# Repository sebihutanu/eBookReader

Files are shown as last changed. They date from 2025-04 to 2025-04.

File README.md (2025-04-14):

# OpenBook 

<p align="center">
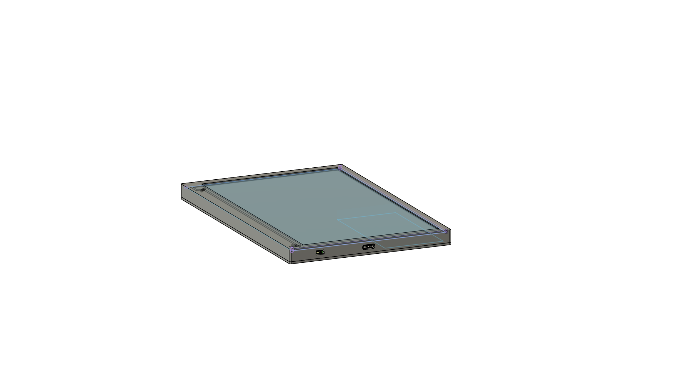
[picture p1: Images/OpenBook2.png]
  
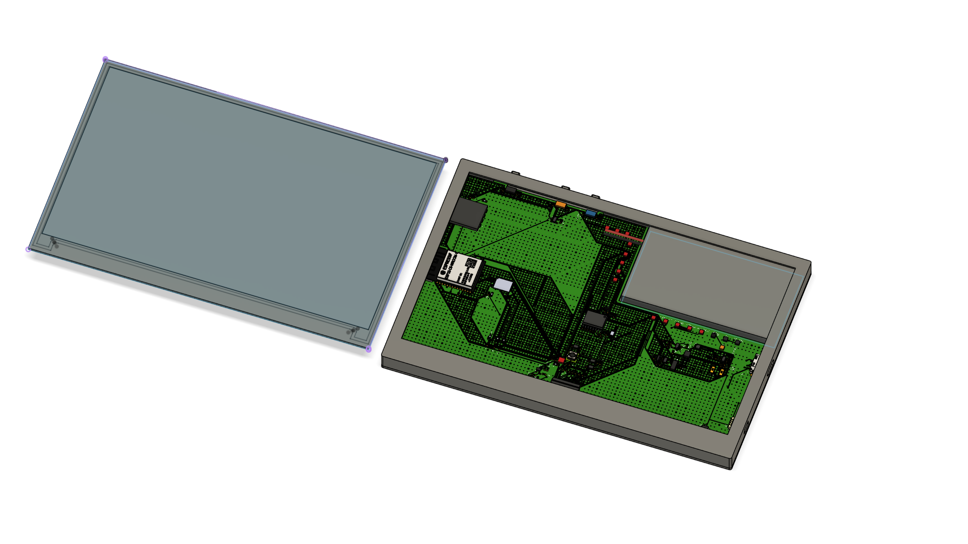
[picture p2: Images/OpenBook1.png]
  
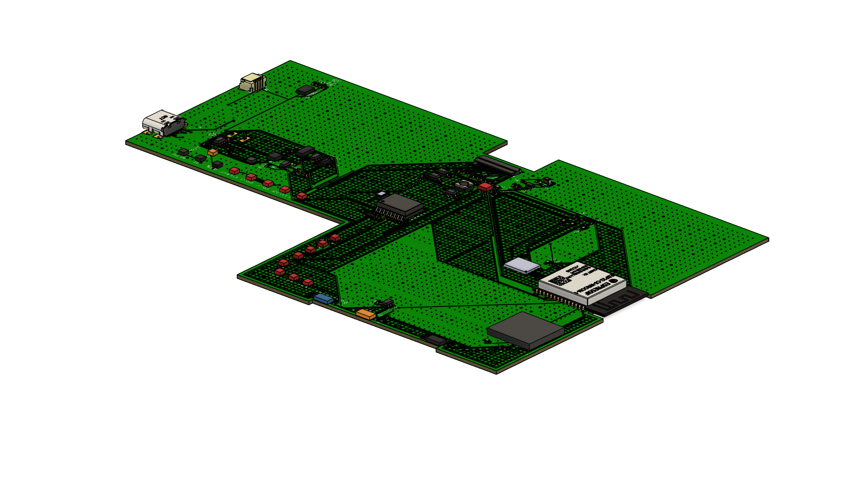
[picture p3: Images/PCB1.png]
  
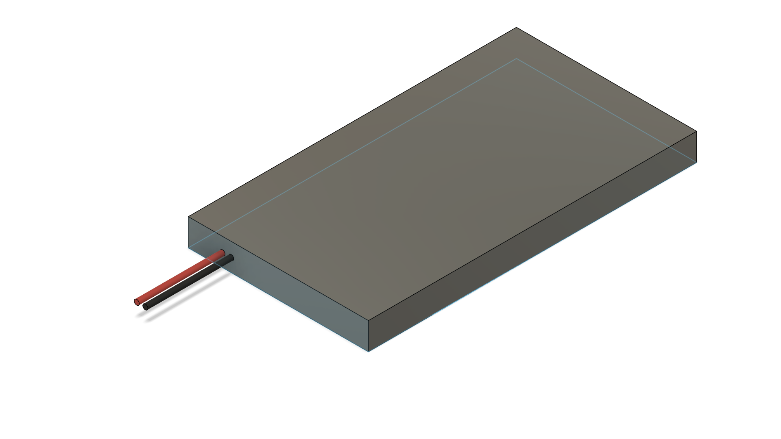
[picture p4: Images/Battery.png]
  
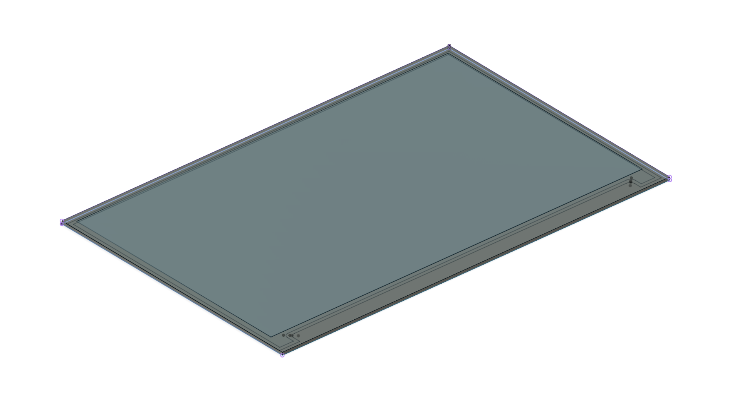
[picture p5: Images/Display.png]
  
</p>

## Implementation Steps

### Schematic Design
I used all the required modules (ESP32-C6, BME688, RTC, Display, etc.) based on the reference schematic. I maintained consistent net naming and used components from the provided library.

### Component Placement
I followed the recommended placement, especially for the ESP32 module (antenna area), buttons, USB port, and display header. All components were placed on the TOP layer, as required.

### Manual Routing
Power traces (3V3, VBAT, VBUS, VUSB, VCC, EPD_3V3, EPD_3V3_C) were routed using a width of 0.3 mm, and signal traces were routed with 0.15 mm width.

### Ground Planes & Via Stitching
I created ground planes on both Top and Bottom layers, connected through via stitching. The area under the ESP32 antenna was excluded (no copper or vias) to ensure proper wireless performance.

### Silkscreen & Test Pads
All components were labeled using only their reference designators (R1, C1, etc.) without values. Test pads were clearly labeled in silkscreen (TX, RX, MISO, VBAT, GND, etc.).

### 3D Model & Enclosure
The final 3D model includes the PCB, display, battery (modeled based on datasheet dimensions), and the official provided enclosure. I verified the alignment of the USB port, buttons, and display header with the housing.

## Component List

- **ESP32-C6-WROOM-1-N8**: Main microcontroller. Supports Wi-Fi 6 (2.4GHz), Bluetooth 5, Thread, and Zigbee. Used for control logic and communication. 
    - **Price**: 14.70 RON
    - **Quantity**: 1
    - **Link**: https://ro.mouser.com/datasheet/2/891/Espressif_ESP32_C6_WROOM_1__Datasheet_V0_1_PRELIMI-3239987.pdf
    - **Datasheet**: https://ro.mouser.com/ProductDetail/Espressif-Systems/ESP32-C6-WROOM-1-N8?qs=8Wlm6%252BaMh8ST02Gmwp74cw%3D%3D

- **W25Q512JVEIQ**: 64MB NOR flash memory. Stores firmware, assets, or user data. Communicates via SPI.
    - **Price**: 28.91 RON
    - **Quantity**: 1
    - **Link**: https://ro.mouser.com/ProductDetail/Winbond/W25Q512JVEIQ?qs=l7cgNqFNU1jw6svr3at6tA%3D%3D
    - **Datasheet**: https://ro.mouser.com/datasheet/2/949/Winbond_W25Q512JV_Datasheet-3240039.pdf

- **MAX17048G+T10**: Fuel gauge IC. Provides battery charge level monitoring via I2C.
    - **Price**: 21.19 RON
    - **Quantity**: 1
    - **Link**: https://ro.mouser.com/ProductDetail/Analog-Devices-Maxim-Integrated/MAX17048G%2bT10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
    - **Datasheet**: https://ro.mouser.com/datasheet/2/609/MAX17048_MAX17049-3469099.pdf

- **MCP73831**: Li-Ion/Li-Poly battery charging IC. Controls charging current and status indication.
    - **Price**: 3.72 RON
    - **Quantity**: 1
    - **Link**: https://ro.mouser.com/ProductDetail/Microchip-Technology/MCP73831-2ACI-MC?qs=hH%252BOa0VZEiBneYTVdpuVdg%3D%3D
    - **Datasheet**: https://ro.mouser.com/datasheet/2/268/MCP73831_Family_Data_Sheet_DS20001984H-3441711.pdf

- **XC6220A331MR-G**: Low-dropout (LDO) voltage regulator. Converts USB input (5V) to stable 3.3V for the system.
    - **Price**: 2.50 RON
    - **Quantity**: 1
    - **Link**: https://ro.mouser.com/ProductDetail/Torex-Semiconductor/XC6220A331MR-G?qs=AsjdqWjXhJ8ZSWznL1J0gg%3D%3D
    - **Datasheet**: https://ro.mouser.com/datasheet/2/760/xc6220-3371556.pdf

- **DS3231SN#**: High-accuracy real-time clock (RTC) with battery backup. Communicates over I2C.
    - **Price**: 7.23 RON
    - **Quantity**: 1
    - **Link**: https://ro.mouser.com/ProductDetail/Maxim-Integrated/DS3231SN%23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
    - **Datasheet**: https://ro.mouser.com/datasheet/2/609/DS3231-DS3231M-DS3231S

- **BME688 (ESP32_WROVER_BME688)**: Environmental sensor. Measures temperature, humidity, pressure, and gas (VOC). Uses I2C.
    - **Price**: 48.90 RON
    - **Quantity**: 1
    - **Link**: https://ro.mouser.com/ProductDetail/Bosch-Sensortec/BME688?qs=IS%252B4QmGtzzqQoVDscqwx3A%3D%3D
    - **Datasheet**: https://ro.mouser.com/datasheet/2/783/bst_bme688_fl000-2307034.pdf

- **CPH3225A**: Supercapacitor used for RTC backup power.
    - **Price**: 11.04 RON
    - **Quantity**: 1
    - **Link**: https://ro.mouser.com/ProductDetail/Seiko-Semiconductors/CPH3225A?qs=3etwrb1wR%252BhUOph6lAO7eg%3D%3D
    - **Datasheet**: https://ro.mouser.com/datasheet/2/360/Seiko_Instruments_MicroBattery_E_20230330_2024Jan_-3561061.pdf

- **744043680IND_4828-WE-TPC_WRE**: Inductor (68µH). Used for filtering or part of the power supply circuit.
    - **Price**: 6.44 RON
    - **Quantity**: 1
    - **Link**: https://ro.mouser.com/ProductDetail/Wurth-Elektronik/744043680?qs=PGXP4M47uW6VkZq%252BkzjrHA%3D%3D
    - **Datasheet**: https://www.we-online.com/components/products/datasheet/744043680.pdf

- **MBR0530**: Schottky diodes. Used for reverse voltage protection and power path steering.
    - **Price**: 0.90 RON
    - **Quantity**: 3
    - **Link**: https://ro.mouser.com/ProductDetail/onsemi/MBR0530T3G?qs=3JMERSakebpEmdUS6GetdQ%3D%3D
    - **Datasheet**: https://www.onsemi.com/PowerSolutions/product.do?id=MBR0530T3G

- **BD5229G-TR**: Voltage detector. Used for power-on reset or system supervisory functions.
    - **Price**: 3.72 RON
    - **Quantity**: 1
    - **Link**: https://ro.mouser.com/ProductDetail/ROHM-Semiconductor/BD5229G-TR?qs=4kLU8WoGk0vvnhrrYwdszw%3D%3D
    - **Datasheet**: https://fscdn.rohm.com/en/products/databook/datasheet/ic/power/voltage_detector/bd52xxg-e.pdf

- **SI1308EDL-T1-GE3**: N-channel MOSFET. Used for switching or power control.
    - **Price**: 2.07 RON
    - **Quantity**: 1
    - **Link**: https://ro.mouser.com/ProductDetail/Vishay-Semiconductors/SI1308EDL-T1-GE3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
    - **Datasheet**: https://www.vishay.com/doc?63399

- **DMG2305UX**: P-channel MOSFET. Used in power switching or display driving.
    - **Price**: 0.95 RON
    - **Quantity**: 2
    - **Link**: https://ro.mouser.com/ProductDetail/Diodes-Incorporated/DMG2305UX-7?qs=L1DZKBg7t5F%2FNBHrjfxC%252Bg%3D%3D
    - **Datasheet**: https://www.diodes.com/assets/Datasheets/DMG2305UX.pdf

- **USBLC6-2SC6Y**: ESD protection array for USB lines.
    - **Price**: 2.16 RON
    - **Quantity**: 1
    - **Link**: https://ro.mouser.com/ProductDetail/STMicroelectronics/USBLC6-2SC6Y?qs=gNDSiZmRJS%2FOgDexvXkdow%3D%3D
    - **Datasheet**: https://ro.mouser.com/datasheet/2/389/usblc6_2sc6y-1852505.pdf

- **PGB1010603MR**: ESD suppressor / protection component for various I/O lines.
    - **Price**: 1.98 RON
    - **Quantity**: 6
    - **Link**: https://ro.mouser.com/ProductDetail/Littelfuse/PGB1010603MR?qs=gu7KAQ731URLg4GSnNNN7Q%3D%3D
    - **Datasheet**: https://www.littelfuse.com/assetdocs/pulseguard-esd-suppressors-pgb1-datasheet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

- **TPTP20R**: Test pads. Used for debugging and electrical measurements (e.g. TX, RX, GND, etc.).

- **FH34SRJ-24S-0.5SH(99)**: FPC connector. Used for connecting the e-paper display.
    - **Price**: 12.87 RON
    - **Quantity**: 1
    - **Link**: https://ro.mouser.com/ProductDetail/Hirose-Connector/FH34SRJ-24S-0.5SH99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
    - **Datasheet**: https://ro.mouser.com/datasheet/2/185/FH34SRJ_24S_0_5SH_99__CL0580_1255_6_99_2DDrawing_0-1615044.pdf

- **SAMACSYS_PARTS_USB4110-GF-A**: USB Type-C connector. Used for charging and potential data communication.
    - **Price**: 5.84 RON
    - **Quantity**: 1
    - **Link**: https://ro.mouser.com/ProductDetail/GCT/USB4110-GF-A?qs=KUoIvG%2F9IlYiZvIXQjyJeA%3D%3D
    - **Datasheet**: https://ro.mouser.com/datasheet/2/837/GCT_USB4110_Product_Drawing___20k_cycles-3455479.pdf

- **112A-TAAR-R03_ATTEND3DMODEL**: MicroSD card connector (Push-Push type).
    - **Price**: 7.08 RON
    - **Quantity**: 1
    - **Link**: https://www.digikey.in/en/products/detail/attend-technology/112A-TAAR-R03/17633923
    - **Datasheet**: https://www.attend.com.tw/data/download/file/112A-TAAR-R03_Spec.pdf

- **QWIIC_CONNECTORJS-1MM**: Qwiic I2C connector. Simplifies connecting I2C peripherals.
    - **Price**: 2.30 RON
    - **Quantity**: 1
    - **Link**: https://www.sparkfun.com/qwiic-jst-connector-smd-4-pin-horizontal.html
    - **Datasheet**: https://cdn.sparkfun.com/assets/parts/1/2/2/8/9/Qwiic_Connector_Datasheet.pdf

- **BUTTON_CUSYOMV1**: Push buttons for user input. Includes RESET, BOOT, and FUNCTION buttons.

- **SJ**: Solder jumper. Used to configure hardware options or break/join signals manually.
    - **Price**: 0.55 RON
    - **Quantity**: 1
    - **Link**: https://ro.mouser.com/ProductDetail/Walsin/WR08X000-PGL?qs=1mbolxNpo8eMafhL38cnrw%3D%3D
    - **Datasheet**: https://www.farnell.com/datasheets/2813407.pdf

- **ESP32C6_VARISTORCN1812**: Varistor. Protects against voltage spikes on power lines.
    - **Price**: 2.68 RON
    - **Quantity**: 1
    - **Link**: https://ro.mouser.com/ProductDetail/Bourns/MOV-14D101K?qs=CQ3B1E%252BbPs1zZItCYuJaag%3D%3D
    - **Datasheet**: https://www.mouser.com/datasheet/2/54/MOV14D-57555.pdf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

- **ESP32_WROVER_AVX (SD0805S020S1R0)**: Schottky diode (another variant). Also used for power line protection.
    - **Price**: 1.46 RON
    - **Quantity**: 1
    - **Link**: https://ro.mouser.com/ProductDetail/KYOCERA-AVX/SD0805S020S1R0?qs=jCA%252BPfw4LHbpkAoSnwrdjw%3D%3D
    - **Datasheet**: https://ro.mouser.com/datasheet/2/40/schottky-3165252.pdf

- **ADAFRUIT_LEDCHIP-LED0603**: Surface-mount LED (0603). Used as charge indicator or status LED.
    - **Price**: 0.50 RON
    - **Quantity**: 1
    - **Link**: https://www.niden.ro/led-uri-smd/4560-led-smd-0603-alb-rece.html
    - **Datasheet**: https://www.mouser.com/datasheet/2/423/LSM0603472V_(1)-1379786.pdf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

- **EAGLE-LTSPICE_CC0402 / RR0402 / RCL_CPOL-EUCT3528**: Capacitors and resistors in SMD packages. Used for decoupling, filtering, and biasing.
    - **Price**: 0.10 RON
    - **Quantity**: 1
    - **Link**: https://www.digikey.com/en/products/detail/rohm-semiconductor/CC0402/1000000
    - **Datasheet**: https://www.rohm.com/datasheet/CC0402

- **CC0402**: Capacitor (0402 package). Used for decoupling and filtering.
    - **Price**: 0.52 RON
    - **Quantity**: 24
    - **Link**: https://ro.mouser.com/ProductDetail/TAIYO-YUDEN/MCASU105SCG100JFNA01?qs=HFfMDpzxxd3IzDXquDJtfA%3D%3D
    - **Datasheet**: https://ro.mouser.com/datasheet/2/396/TAIYO_YUDEN_04_29_2024_MCASU105SCG100JFNA01_SS-3451431.pdf

- **RR0402**: Resistor (0402 package). Used for pull-up/pull-down or biasing.
    - **Price**: 0.27 RON
    - **Quantity**: 24
    - **Link**: https://ro.mouser.com/ProductDetail/Vishay-Dale/CRCW04020000Z0EEHP?qs=Imq1NPwxi74NTc567q7flQ%3D%3D
    - **Datasheet**: https://www.vishay.com/doc?20043

- **RCL_CPOL-EUCT3528**: Capacitor (EUCT3528 package). Used for decoupling and filtering.
    - **Price**: 6.50 RON
    - **Quantity**: 1
    - **Link**: https://ro.mouser.com/ProductDetail/Vishay-Sprague/TX3B336K016C1000?qs=HFfMDpzxxd327XT3TleiYg%3D%3D
    - **Datasheet**: https://www.vishay.com/doc?40283

- **Battery**: 3.7V Li-Ion battery (not included in the schematic). Used for powering the device when not connected to USB.
    - **Price**: 29.50 RON
    - **Quantity**: 1
    - **Link**: https://www.tme.eu/Document/e0683d8c34e6d878124489f71bffb6ee/cel0014.pdf
    - **Datasheet**: https://www.tme.eu/Document/e0683d8c34e6d878124489f71bffb6ee/cel0014.pdf

- **Display**: E-paper display (not included in the schematic). Used for displaying information to the user.
    - **Price**: 258.85 RON
    - **Quantity**: 1
    - **Link**: https://www.waveshare.com/7.5inch-e-paper-hat.htm
    - **Datasheet**: https://files.waveshare.com/upload/6/60/7.5inch_e-Paper_V2_Specification.pdf
    
> **Total Cost**: 485.50 RON (approx. 100 EUR)

> **Note:** All standard resistors and capacitors are SMD 0402 unless otherwise specified. Decoupling capacitors (100nF) are placed close to IC power pins for stability.

## Block Diagram

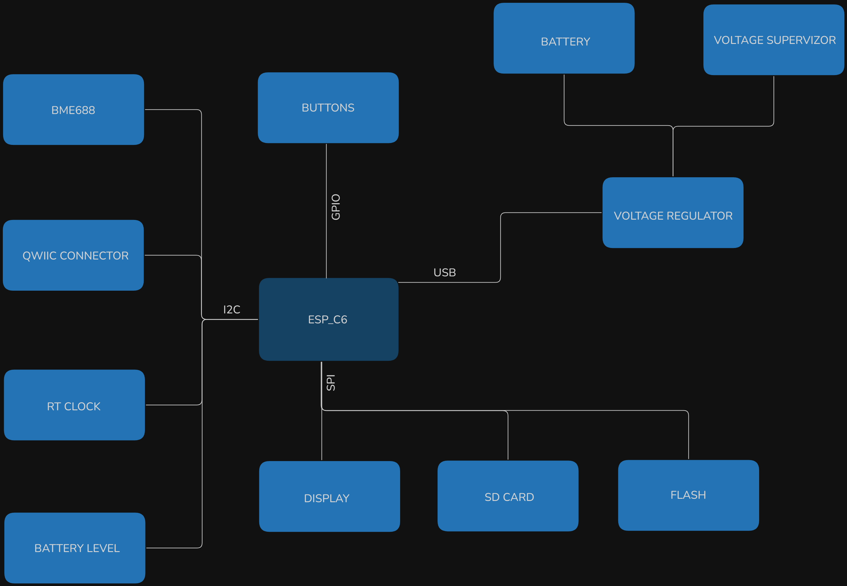
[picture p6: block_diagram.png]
Block Diagram


## ESP32-C6 Pin Utilization

| ESP32-C6 Pin | Signal Name | Connected Component | Description / Purpose |
|---|---|---|---|
| EN | RESET | - | Reset input, active HIGH; used to restart the microcontroller |
| GPIO0 | INT_RTC | RTC (DS3231) | External interrupt input from RTC alarm |
| GPIO1 | 32KHZ | RTC (DS3231) | 32 kHz reference clock from RTC |
| GPIO2 | MISO | SD card / Flash | SPI MISO line for data input |
| GPIO3 | EPD_BUSY | E-paper display | Busy status from EPD module |
| GPIO4 | SS_SD | SD card | Chip select for SD card on SPI |
| GPIO5 | EPD_DC | E-paper display | Data/command control signal for EPD |
| GPIO6 | SCK | SPI bus | Serial clock for SPI communication |
| GPIO7 | MOSI | SPI bus | SPI data output |
| GPIO8 | GPIO8 | - | Unused general-purpose pin (test/debug) |
| GPIO9 | IO/BOOT | Push-button | Used to enter bootloader mode for programming |
| GPIO10 | EPD_CS | E-paper display | Chip select for EPD module |
| GPIO11 | FLASH_CS | External flash (W25Q512) | Chip select for SPI flash memory |
| GPIO12 | USB_D- | USB-C connector | USB differential data line (negative) |
| GPIO13 | USB_D+ | USB-C connector | USB differential data line (positive) |
| GPIO15 | IO/CHANGE | Push-button | General-purpose button input |
| GPIO16 (TXD) | TX | UART | Serial transmission line |
| GPIO17 (RXD) | RX | UART | Serial reception line |
| GPIO18 | RTC_RST | RTC (DS3231) | Reset control for RTC |
| GPIO19 | I2C_RST | I2C devices | I2C reset or control signal |
| GPIO20 | EPD_3V3_C | E-paper display | Power control or monitoring line for EPD |
| GPIO21 | SDA | I2C devices (BME688, Fuel Gauge) | I2C data line for sensors and peripherals |
| GPIO22 | SCL | I2C devices (BME688, Fuel Gauge) | I2C clock line for sensors and peripherals |
| GPIO23 | EPD_RST | E-paper display | Reset signal for the EPD display |

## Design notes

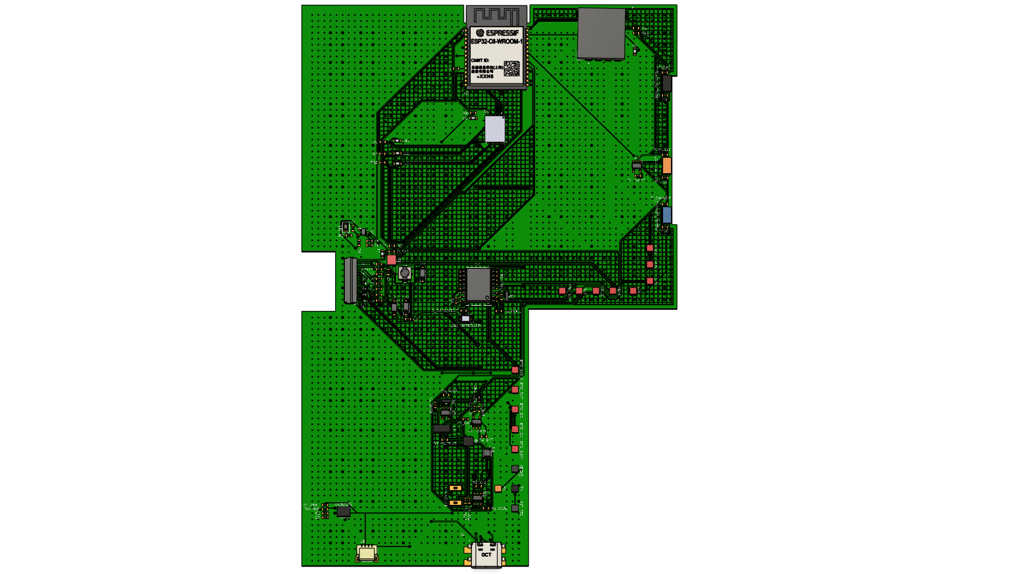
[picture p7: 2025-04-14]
Images/PCB2.png

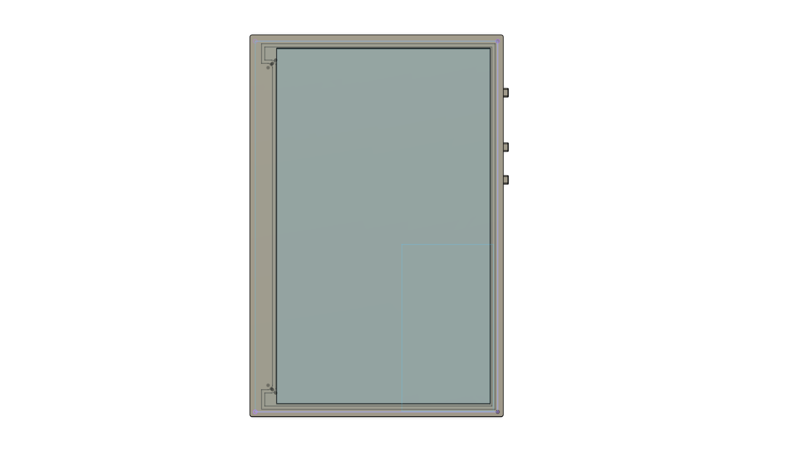
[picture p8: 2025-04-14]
Images/OpenBook3.png

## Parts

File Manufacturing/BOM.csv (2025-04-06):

Qty | Value | Device | Package | Parts | Description | ARROW_PART_NUMBER | ARROW_PRICE-STOCK | AVAILABILITY | CENTROID_NOT_SPECIFIED | CHECK_PRICES | COPYRIGHT | DATASHEET | DESCRIPTION | DIGIKEY_DESCRIPTION | DIGIKEY_PART_NUMBER | HEIGHT | LEAD_FREE | MANUFACTURER_NAME | MANUFACTURER_PART_NUMBER | MF | MFR_NAME | MOUSER_PART_NUMBER | MOUSER_PRICE-STOCK | MP | MPN | PACKAGE | POPULARITY | PREFIX | PRICE | PROD_ID | PURCHASE-URL | ROHS | SNAPEDA_LINK | SPICEMODEL | SPICEPREFIX | TEMPERATURE_RANGE_HIGH | TEMPERATURE_RANGE_LOW | TP_SIGNAL_NAME | VALUE
1 |  | ADAFRUIT_LEDCHIP-LED0603 | ADAFRUIT_CHIP-LED0603 | CHG_LED | LED
1 |  | EAGLE-LTSPICE_CC0402 | EAGLE-LTSPICE_C0402 | C2 | CAPACITOR, European symbol |  |  |  |  |  |  |  |  |  |  |  |  |  |  |  |  |  |  |  |  |  |  |  |  |  |  |  |  | NONE | C
6 |  | ESP32_WROVER_EAGLE-LTSPICE_RR0402 | ESP32_WROVER_EAGLE-LTSPICE_R0402 | R5, R7, R8, R9, R10, R12 | RESISTOR, European symbol |  |  |  |  |  |  |  |  |  |  |  |  |  |  |  |  |  |  |  |  |  |  |  |  |  |  |  |  | NONE | R
1 |  | SJ | SJ | SJ1 | SMD solder JUMPER |  |  |  |  |  |  |  |  |  |  |  |  |  |  |  |  |  |  |  |  |  | 3
1 | 0.1uF/50V | EAGLE-LTSPICE_CC0402 | EAGLE-LTSPICE_C0402 | EPD_C5 | CAPACITOR, European symbol |  |  |  |  |  |  |  |  |  |  |  |  |  |  |  |  |  |  |  |  |  |  |  |  |  |  |  |  | NONE | C
1 | 0.47 | ESP32_WROVER_EAGLE-LTSPICE_RR0402 | ESP32_WROVER_EAGLE-LTSPICE_R0402 | R3 | RESISTOR, European symbol |  |  |  |  |  |  |  |  |  |  |  |  |  |  |  |  |  |  |  |  |  |  |  |  |  |  |  |  | NONE | R
1 | 100K | ESP32_WROVER_EAGLE-LTSPICE_RR0402 | ESP32_WROVER_EAGLE-LTSPICE_R0402 | R1_PWRUSB | RESISTOR, European symbol |  |  |  |  |  |  |  |  |  |  |  |  |  |  |  |  |  |  |  |  |  |  |  |  |  |  |  |  | NONE | R
6 | 100nF | EAGLE-LTSPICE_CC0402 | EAGLE-LTSPICE_C0402 | C1, C4_USB, C6, C8, C10, C_DELAY | CAPACITOR, European symbol |  |  |  |  |  |  |  |  |  |  |  |  |  |  |  |  |  |  |  |  |  |  |  |  |  |  |  |  | NONE | C
1 | 100nF | ESP32_WROVER_EAGLE-LTSPICE_CC0402 | ESP32_WROVER_EAGLE-LTSPICE_C0402 | C9 | CAPACITOR, European symbol |  |  |  |  |  |  |  |  |  |  |  |  |  |  |  |  |  |  |  |  |  |  |  |  |  |  |  |  | NONE | C
1 | 100uF TANT | RCL_CPOL-EUCT3528 | RCL_CT3528 | C3 | POLARIZED CAPACITOR, European symbol |  |  |  |  |  |  |  |  |  |  |  |  |  |  |  |  |  |  |  |  |  | 0 |  |  |  |  |  |  |  | C
10 | 10K | ESP32_WROVER_EAGLE-LTSPICE_RR0402 | ESP32_WROVER_EAGLE-LTSPICE_R0402 | R1, R1_PINH, R1_PINH1, R2-PINH, R2-PINH1, R4, R_BOOT, R_CHANGE, R_CL1, R_RESET | RESISTOR, European symbol |  |  |  |  |  |  |  |  |  |  |  |  |  |  |  |  |  |  |  |  |  |  |  |  |  |  |  |  | NONE | R
1 | 10uF | ESP32_WROVER_EAGLE-LTSPICE_CC0402 | ESP32_WROVER_EAGLE-LTSPICE_C0402 | C7 | CAPACITOR, European symbol |  |  |  |  |  |  |  |  |  |  |  |  |  |  |  |  |  |  |  |  |  |  |  |  |  |  |  |  | NONE | C
1 | 112A-TAAR-R03_ATTEND3DMODEL | 112A-TAAR-R03_ATTEND3DMODEL | 112ATAARR03ATTEND | J4 | Micro SD Card Socket, Push-Push Type, Top Mount, SMT, H=1.83mm, 10u
1 | 15 | ESP32_WROVER_EAGLE-LTSPICE_RR0402 | ESP32_WROVER_EAGLE-LTSPICE_R0402 | R_CAPACITOR | RESISTOR, European symbol |  |  |  |  |  |  |  |  |  |  |  |  |  |  |  |  |  |  |  |  |  |  |  |  |  |  |  |  | NONE | R
1 | 1uF | EAGLE-LTSPICE_CC0402 | EAGLE-LTSPICE_C0402 | C5 | CAPACITOR, European symbol |  |  |  |  |  |  |  |  |  |  |  |  |  |  |  |  |  |  |  |  |  |  |  |  |  |  |  |  | NONE | C
9 | 1uF/50V | EAGLE-LTSPICE_CC0402 | EAGLE-LTSPICE_C0402 | EPD_C1, EPD_C2, EPD_C6, EPD_C7, EPD_C8, EPD_C9, EPD_C10, EPD_C11, EPD_C12 | CAPACITOR, European symbol |  |  |  |  |  |  |  |  |  |  |  |  |  |  |  |  |  |  |  |  |  |  |  |  |  |  |  |  | NONE | C
1 | 2.2 | ESP32_WROVER_EAGLE-LTSPICE_RR0402 | ESP32_WROVER_EAGLE-LTSPICE_R0402 | R2 | RESISTOR, European symbol |  |  |  |  |  |  |  |  |  |  |  |  |  |  |  |  |  |  |  |  |  |  |  |  |  |  |  |  | NONE | R
1 | 200 | ESP32_WROVER_EAGLE-LTSPICE_RR0402 | ESP32_WROVER_EAGLE-LTSPICE_R0402 | R1_BAT | RESISTOR, European symbol |  |  |  |  |  |  |  |  |  |  |  |  |  |  |  |  |  |  |  |  |  |  |  |  |  |  |  |  | NONE | R
2 | 20V/4.2A/52mO/1.4W | ESP32_WROVER_SPARKFUN-DISCRETESEMI_MOSFET_PCH-DMG2305UX-7 | ESP32_WROVER_SPARKFUN-DISCRETESEMI_SOT23-3 | Q1, Q2 | P-channel MOSFETs |  |  |  |  |  |  |  |  |  |  |  |  |  |  |  |  |  |  |  |  |  |  |  |  | TRAN-14388 |  |  |  |  |  |  |  |  | 20V/4.2A/52mO/1.4W
1 | 2K | ESP32_WROVER_EAGLE-LTSPICE_RR0402 | ESP32_WROVER_EAGLE-LTSPICE_R0402 | R2_BAT | RESISTOR, European symbol |  |  |  |  |  |  |  |  |  |  |  |  |  |  |  |  |  |  |  |  |  |  |  |  |  |  |  |  | NONE | R
4 | 4.7uF | EAGLE-LTSPICE_CC0402 | EAGLE-LTSPICE_C0402 | C1_BAT, C1_BAT1, C2_BAT, C5_USB | CAPACITOR, European symbol |  |  |  |  |  |  |  |  |  |  |  |  |  |  |  |  |  |  |  |  |  |  |  |  |  |  |  |  | NONE | C
1 | 4.7uF | ESP32_WROVER_EAGLE-LTSPICE_CC0402 | ESP32_WROVER_EAGLE-LTSPICE_C0402 | C1_BAT2 | CAPACITOR, European symbol |  |  |  |  |  |  |  |  |  |  |  |  |  |  |  |  |  |  |  |  |  |  |  |  |  |  |  |  | NONE | C
1 | 4.7uF/25V | EAGLE-LTSPICE_CC0402 | EAGLE-LTSPICE_C0402 | C4 | CAPACITOR, European symbol |  |  |  |  |  |  |  |  |  |  |  |  |  |  |  |  |  |  |  |  |  |  |  |  |  |  |  |  | NONE | C
2 | 5k1 | ESP32_WROVER_EAGLE-LTSPICE_RR0402 | ESP32_WROVER_EAGLE-LTSPICE_R0402 | R2-USB, R2-USB1 | RESISTOR, European symbol |  |  |  |  |  |  |  |  |  |  |  |  |  |  |  |  |  |  |  |  |  |  |  |  |  |  |  |  | NONE | R
1 | 744043680IND_4828-WE-TPC_WRE | 744043680IND_4828-WE-TPC_WRE | IND_4828-WE-TPC_WRE | L1 |  |  |  |  |  |  | Copyright (C) 2024 Ultra Librarian. All rights reserved. |  |  |  |  |  |  |  | 744043680 |  | Wurth Electronics
1 | BD5229G-TR | BD5229G-TR | SOT95P280X125-5N | IC1 | Voltage Detector with Adjustable Delay Time: CMOS processes are utilized to develop high precision, low current consumption CMOS reset ICs that allow arbitrary setting of the delay time. The extensive lineup includes both Nch Open Drain and CMOS output types in a wide range of detection voltages (from 2.3V to 6.0V, in 0.1V steps), enabling selection of the ideal solution based on customer requirements. In addition, the entire series is of course both lead-free and RoHS-compliant. |  |  |  |  |  |  |  | Voltage Detector with Adjustable Delay Time: CMOS processes are utilized to develop high precision | low current consumption CMOS reset ICs that allow arbitrary setting of the delay time. The extensive lineup includes both Nch Open Drain and CMOS output types in a wide range of detection voltages (from 2.3V to 6.0V | in 0.1V steps) | enabling selection of the ideal solution based on customer requirements. In addition | the entire series is of course both lead-free and RoHS-compliant. |  |  | 1.25mm |  | ROHM Semiconductor | BD5229G-TR |  |  | 755-BD5229G-TR | https://www.mouser.co.uk/ProductDetail/ROHM-Semiconductor/BD5229G-TR?qs=4kLU8WoGk0vvnhrrYwdszw%3D%3D
3 | BUTTON_CUSYOMV1 | BUTTON_CUSYOMV1 | MYBUTTON | BOOT_BUTTON, CHANGE_BUTTON, RESET_BUTTON
1 | CPH3225A | CPH3225A | CAPCP3225X100N | C10_SUPERCAP | Cap 0.011F 3.3V 1210 Flat Check availability |  |  | Not in stock |  | https://www.snapeda.com/parts/CPH3225A/Seiko+Instruments/view-part/?ref=eda |  |  | 11 mF (EDLC) Supercapacitor 3.3 V 1210 (3225 Metric) - - |  |  |  |  |  |  | Seiko Instruments |  |  |  | CPH3225A |  | 1210 Seiko |  |  | None |  | https://www.snapeda.com/api/url_track_click_mouser/?unipart_id=562593&manufacturer=Seiko Instruments&part_name=CPH3225A&search_term=None |  | https://www.snapeda.com/parts/CPH3225A/Seiko+Instruments/view-part/?ref=snap
1 | DS3231SN# | DS3231SN# | SOIC127P1032X265-16N | U3 | Real Time Clock Serial 16-Pin SOIC W T/R Check availability |  |  | In Stock |  | https://www.snapeda.com/parts/DS3231SN%23/Analog+Devices/view-part/?ref=eda |  |  | Extremely Accurate I²C-Integrated RTC/TCXO/Crystal |  |  |  |  |  |  | Analog Devices |  |  |  | DS3231SN# |  | SOIC-16 Maxim |  |  | None |  | https://www.snapeda.com/api/url_track_click_mouser/?unipart_id=99048&manufacturer=Analog Devices&part_name=DS3231SN#&search_term=None |  | https://www.snapeda.com/parts/DS3231SN%23/Analog+Devices/view-part/?ref=snap
1 | ESP32-C6-WROOM-1-N8 | ESP32-C6-WROOM-1-N8 | XCVR_ESP32-C6-WROOM-1-N8 | U2 | Check availability |  |  | In Stock |  | https://www.snapeda.com/parts/ESP32-C6-WROOM-1-N8/Espressif+Systems/view-part/?ref=eda |  |  | Multiprotocol Modules ESP32-C6 module | Wi-Fi 6 in 2.4 GHz band | Bluetooth 5 | Zigbee 3.0 and Thread. ESP34-WROOM Compatible - ENGINEERING SAMPLE |  |  |  |  |  |  | Espressif Systems |  |  |  | ESP32-C6-WROOM-1-N8 |  | None |  |  | None |  |  |  | https://www.snapeda.com/parts/ESP32-C6-WROOM-1-N8/Espressif+Systems/view-part/?ref=snap
1 | ESP32C6_VARISTORCN1812 | ESP32C6_VARISTORCN1812 | ESP32C6_VARISTOR_CT/CN1812 | PFMF.050.1 | VARISTOR |  |  |  |  |  |  |  |  |  |  |  |  |  |  |  |  |  |  |  |  |  | 0
2 | ESP32_WROVER_AVX---SD0805S020S1R0_AVX_SD0805S020S1R0_0_0AVX_SD0805S020S1R0_0_0 | ESP32_WROVER_AVX---SD0805S020S1R0_AVX_SD0805S020S1R0_0_0AVX_SD0805S020S1R0_0_0 | ESP32_WROVER_AVX---SD0805S020S1R0_AVX_SD0805S020S1R0_0 | D2, D7 | Schottky Barrier Rectifier Diode |  |  |  | No |  |  | http://datasheets.avx.com/schottky.pdf |  | DIODE SCHOTTKY 20V 1A 0805 | 478-7800-1-ND |  | yes |  |  | AVX |  | 581-SD0805S020S1R0 |  |  |  | 0805 (2012 metric) |  | D |  |  |  | yes |  |  |  | +125°C | -55°C
1 | ESP32_WROVER_BME680_BME680 | ESP32_WROVER_BME680_BME680 | ESP32_WROVER_BME680_PSON80P300X300X100-8N | SENSOR2 | Integrated Environmental Unit |  |  | Unavailable |  |  |  |  | Integrated Environmental Unit |  |  |  |  |  |  | Bosch Sensortec |  |  |  | BME680 |  | LGA-8 Bosch Tools |  |  | None
1 | ESP32_WROVER_SPARKFUN-IC-POWER_MCP73831 | ESP32_WROVER_SPARKFUN-IC-POWER_MCP73831 | ESP32_WROVER_SPARKFUN-IC-POWER_SOT23-5 | MCP73831 | MCP73831T Li-Ion, Li-Pol Controller |  |  |  |  |  |  |  |  |  |  |  |  |  |  |  |  |  |  |  |  |  |  |  |  | IC-09995
1 | FH34SRJ-24S-0.5SH_99_ | FH34SRJ-24S-0.5SH_99_ | FH34SRJ24S05SH99 | J1 | (0.50mm) Surface Mount, Right Angle |  |  |  |  |  |  |  | 24 Position FFC | FPC Connector Contacts | (0.50mm) Surface Mount | Right Angle |  |  | 1.1mm |  | Hirose | FH34SRJ-24S-0.5SH(99) |  |  | 798-FH34SRJ24S05SH99 | https://www.mouser.co.uk/ProductDetail/Hirose-Connector/FH34SRJ-24S-0.5SH99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
1 | MAX17048G+T10 | MAX17048G+T10 | SON50P200X200X80-9N | U4 | Check availability |  |  | In Stock |  | https://www.snapeda.com/parts/MAX17048G+T10/Analog+Devices/view-part/?ref=eda |  |  | 3µA 1-Cell/2-Cell Fuel Gauge with ModelGauge |  |  |  |  |  |  | Analog Devices |  |  |  | MAX17048G+T10 |  | TDFN-8 Maxim |  |  | None |  | https://www.snapeda.com/api/url_track_click_mouser/?unipart_id=329239&manufacturer=Analog Devices&part_name=MAX17048G+T10&search_term=None |  | https://www.snapeda.com/parts/MAX17048G+T10/Analog+Devices/view-part/?ref=snap
3 | MBR0530 | MBR0530 | SOD3716X135N | D3, D4, D5 | ON SEMICONDUCTOR - MBR0530 - DIODE, SCHOTTKY, 0.5A, 30V, SOD-123 |  |  | In Stock |  | https://www.snapeda.com/parts/MBR0530/Onsemi/view-part/?ref=eda |  |  | Diode Schottky 30 V 500mA Surface Mount SOD-123 |  |  |  |  |  |  | ON Semiconductor |  |  |  | MBR0530 |  | SOD-123-2 ON Semiconductor |  |  | None |  | https://www.snapeda.com/api/url_track_click_mouser/?unipart_id=179458&manufacturer=ON Semiconductor&part_name=MBR0530&search_term=None |  | https://www.snapeda.com/parts/MBR0530/Onsemi/view-part/?ref=snap
6 | PGB1010603MR | PGB1010603MR | DIOC1608X36N | D6, D8, D9, D10, D11, D12 | Check availability |  |  | In Stock |  | https://www.snapeda.com/parts/PGB1010603MR/Littelfuse/view-part/?ref=eda |  |  | 150V (Typ) Clamp - Ipp Tvs Diode Surface Mount 0603 (1608 Metric) |  |  |  |  |  |  | Littelfuse Inc. |  |  |  | PGB1010603MR |  | 0603 Littelfuse Inc. |  |  | None |  | https://www.snapeda.com/api/url_track_click_mouser/?unipart_id=5659453&manufacturer=Littelfuse Inc.&part_name=PGB1010603MR&search_term=None |  | https://www.snapeda.com/parts/PGB1010603MR/Littelfuse/view-part/?ref=snap
1 | QWIIC_RIGHT_ANGLE | QWIIC_CONNECTORJS-1MM | JST04_1MM_RA | J3 | SparkFun I2C Standard Qwiic Connector |  |  |  |  |  |  |  |  |  |  |  |  |  |  |  |  |  |  |  |  |  |  |  |  | CONN-13694 |  |  |  |  |  |  |  |  | QWIIC_RIGHT_ANGLE
1 | SAMACSYS_PARTS_USB4110-GF-A | SAMACSYS_PARTS_USB4110-GF-A | SAMACSYS_PARTS_USB4110GFA | J2 | CONN USB 2.0 TYPE-C R/A SMT |  |  |  |  |  |  |  | CONN USB 2.0 TYPE-C R/A SMT |  |  | 3.26mm |  | GCT (GLOBAL CONNECTOR TECHNOLOGY) | USB4110-GF-A |  |  | 640-USB4110-GF-A | https://www.mouser.co.uk/ProductDetail/GCT/USB4110-GF-A?qs=KUoIvG%2F9IlYiZvIXQjyJeA%3D%3D
1 | SI1308EDL-T1-GE3 | SI1308EDL-T1-GE3 | SOT65P210X110-3N | Q3 | MOSFET N-Ch 30V 1.5A TrenchFET SC70 Vishay Si1308EDL-T1-GE3 N-channel MOSFET Transistor, 1.5 A, 30 V, 3-Pin SC-70 |  |  | In Stock |  | https://www.snapeda.com/parts/SI1308EDL-T1-GE3/Vishay+Siliconix/view-part/?ref=eda |  |  | Si1308EDL-T1-GE3 N-channel MOSFET Transistor | 1.5 A | 30 V | 3-Pin SC-70 | Siliconix / Vishay SI1308EDL-T1-GE3 |  |  |  |  |  |  | Vishay Siliconix |  |  |  | SI1308EDL-T1-GE3 |  | SOT-323 Vishay Semiconductor |  |  | None |  | https://www.snapeda.com/api/url_track_click_mouser/?unipart_id=274603&manufacturer=Vishay Siliconix&part_name=SI1308EDL-T1-GE3&search_term=None |  | https://www.snapeda.com/parts/SI1308EDL-T1-GE3/Vishay+Siliconix/view-part/?ref=snap
17 | TPTP20R | TPTP20R | TP20R | 3V3, EPD_3V3, EPD_3V3_C, EPD_BUSY, EPD_CS, EPD_DC, EPD_RST, GND, INT_RTC, MISO, MOSI, RX, SCK, TP5, TX, VBAT, VBUS | Test pad |  |  |  |  |  |  |  |  |  |  |  |  |  |  |  |  |  |  |  |  |  | 2
1 | USBLC6-2SC6Y | USBLC6-2SC6Y | SOT95P280X145-6N | D1 | Low Cap. ESD Protection Auto SOT-23-6 STMicroelectronics USBLC6-2SC6Y, Dual Uni-Directional TVS Diode Array, 6-Pin SOT-23 |  |  | In Stock |  | https://www.snapeda.com/parts/USBLC6-2SC6Y/STMicroelectronics/view-part/?ref=eda |  |  | 17V Clamp 5A (8/20µs) Ipp Tvs Diode Surface Mount SOT-23-6 |  |  |  |  |  |  | STMicroelectronics |  |  |  | USBLC6-2SC6Y |  | SOT-23-6 STMicroelectronics |  |  | None |  |  |  | https://www.snapeda.com/parts/USBLC6-2SC6Y/STMicroelectronics/view-part/?ref=snap
1 | W25Q512JVEIQ | W25Q512JVEIQ | SON127P600X800X80-9N | U1 | Check availability |  |  | In Stock |  | https://www.snapeda.com/parts/W25Q512JVEIQ/Winbond+Electronics/view-part/?ref=eda |  |  | FLASH - NOR Memory IC 512Mb (64M x 8) SPI - Quad I/O 133 MHz 8-WSON (8x6) |  |  |  |  |  |  | Winbond Electronics |  |  |  | W25Q512JVEIQ |  | Package |  |  | None |  |  |  | https://www.snapeda.com/parts/W25Q512JVEIQ/Winbond+Electronics/view-part/?ref=snap
1 | XC6220A331MR-G | XC6220A331MR-G | SOT95P280X120-5N | IC4 | LDO Voltage Regulators |  |  |  |  |  |  |  | LDO Voltage Regulators |  |  | 1.2mm |  | Torex | XC6220A331MR-G |  |  | 865-XC6220A331MR-G | https://www.mouser.co.uk/ProductDetail/Torex-Semiconductor/XC6220A331MR-G?qs=AsjdqWjXhJ8ZSWznL1J0gg%3D%3D

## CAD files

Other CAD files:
Mechanical/OpenBook Battery.f3d
Mechanical/OpenBook Display.f3d
Mechanical/OpenBook Enclosure.f3d

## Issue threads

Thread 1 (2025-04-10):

Board Outline Clearence

Dratopia18, 2025-04-10:
Urmatoarele componente: CHANGE_BUTTON, RESET_BUTTON, BOOT_BUTTON si SAMACSYS_PARTS_USB4110-GF-A au erori de tip Board Outline Clearance.

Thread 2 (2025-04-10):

Board Outline Clearance

Dratopia18, 2025-04-10:
Urmatoarele componente: CHANGE_BUTTON, RESET_BUTTON si BOOT_BUTTON au erori de tipul Smd-Line, in timp ce SAMACSYS_PARTS_USB4110-GF-A are erori de tipul Smd-Hole.

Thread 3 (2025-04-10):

Problema la ESP32-C6-WROOM-1-N8

Dratopia18, 2025-04-10:
Suprafața PCB-ului de sub antena modulului ESP32-C6-WROOM-1-N8 nu este decupată, ce poate duce la interferente radio. Dorim ca tableta noastra sa aiba cat mai putine probleme in acest sens, asa ca cel mai bine ar fi ca toata suprafata de sub antena modulului sa fie decupata.

Closed 2025-04-14.

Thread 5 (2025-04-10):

Componente lipsa

Dratopia18, 2025-04-10:
Placa PCB 3D are cateva componente lipsa. Aceste componente sunt: Q3 (tranzistorul MOSFET de canal N), PFMF.050.1 (rezistor de tip varistor) si D7 (dioda redresoare de bariera). Fara aceste componente, placa PCB nu va functiona in mod optim. Recomand cu mare caldura ca acestea sa fie puse pe placa.

Closed 2025-04-14.

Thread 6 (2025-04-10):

Conectorul QWIIC

Dratopia18, 2025-04-10:
Conectorul QWIIC este pus cu capul in jos. Desi acesta incape in carcasa si are mufa situata 1:1 cu carcasa noastra, nefiind conectata la placa 3D PCB, aceasta devine o componenta nefunctionala (considerand ca nu poate comunica cu placa). Recomand fie sa rezolve problema si sa puna conectorul cum trebuie, fie sa caute alta componenta QWIIC care sa se potriveasca cu carcasa.

Closed 2025-04-14.

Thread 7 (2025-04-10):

Grosimea placii PCB neadecvata

Dratopia18, 2025-04-10:
Placa PCB are grosimea de 1.6mm, ceea ce este prea gros, fata de grosimea recomandata de 1mm. Recomand modificarea ei, pentru a respecta cerintele proiectului.

Closed 2025-04-14.

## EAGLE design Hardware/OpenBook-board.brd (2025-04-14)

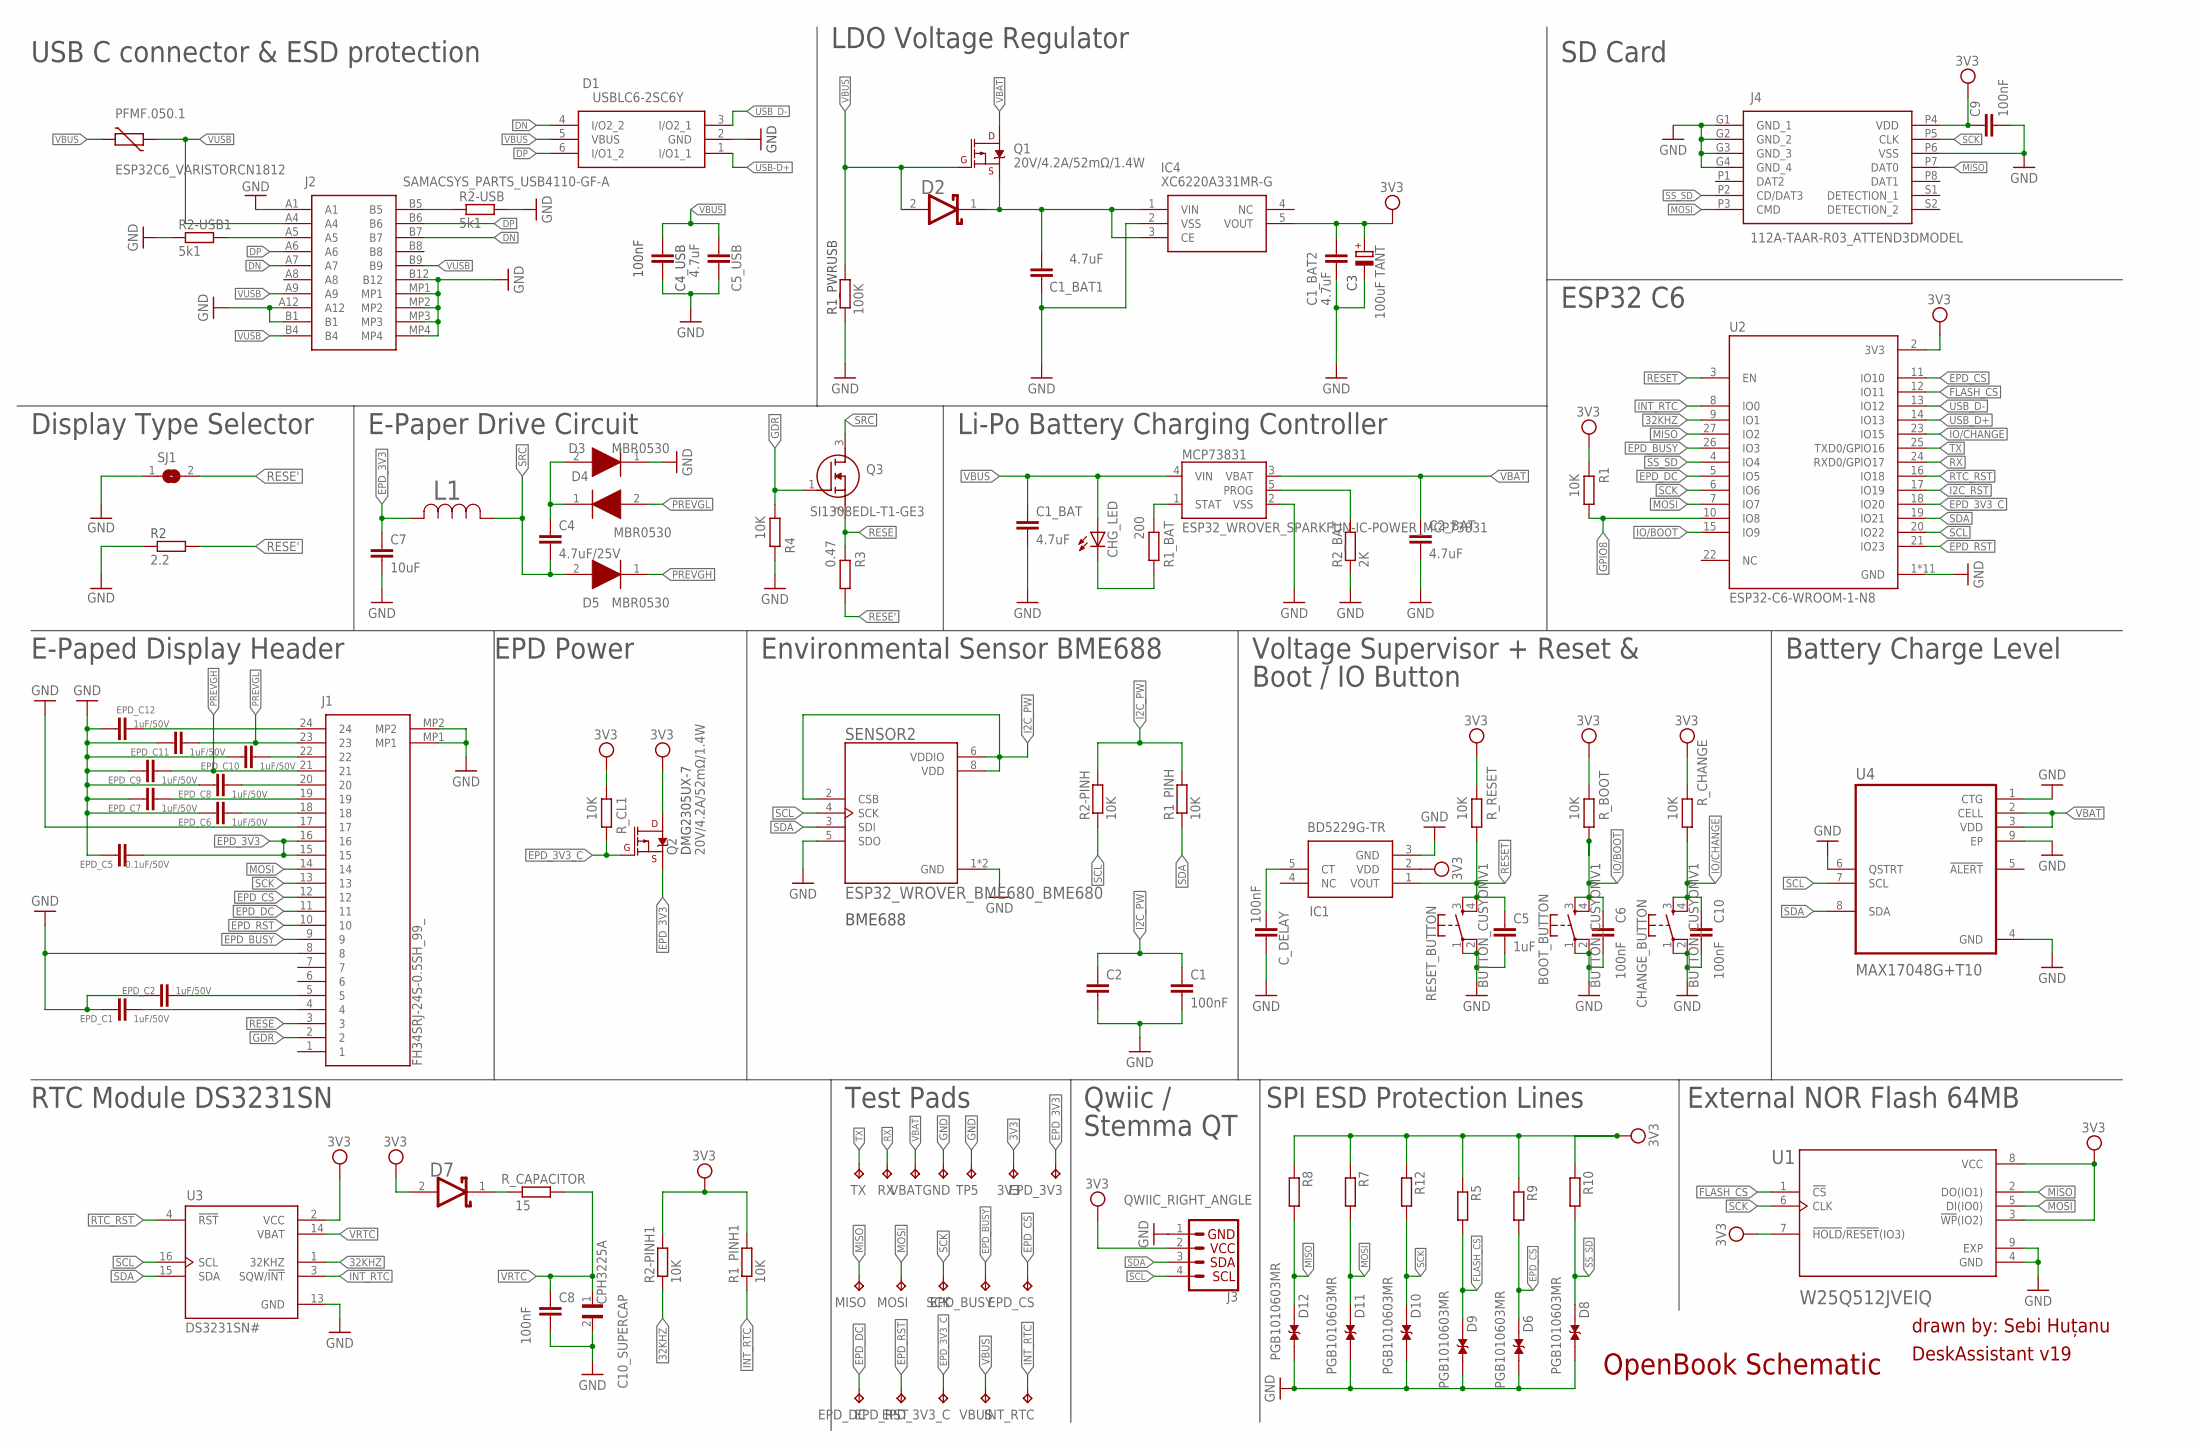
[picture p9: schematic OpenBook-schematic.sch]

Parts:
3V3: TPTP20R; TP20R
BOOT_BUTTON: BUTTON_CUSYOMV1; MYBUTTON
C1, C4_USB, C6, C8, C10: 100nF; EAGLE-LTSPICE_C0402
C1_BAT, C1_BAT1, C2_BAT, C5_USB: 4.7uF; EAGLE-LTSPICE_C0402
C1_BAT2: 4.7uF; ESP32_WROVER_EAGLE-LTSPICE_C0402
C2: EAGLE-LTSPICE_CC0402; EAGLE-LTSPICE_C0402
C3: 100uF TANT; RCL_CT3528
C4: 4.7uF/25V; EAGLE-LTSPICE_C0402
C5: 1uF; EAGLE-LTSPICE_C0402
C7: 10uF; ESP32_WROVER_EAGLE-LTSPICE_C0402
C9: 100nF; ESP32_WROVER_EAGLE-LTSPICE_C0402
C10_SUPERCAP: CPH3225A; CAPCP3225X100N
CHANGE_BUTTON: BUTTON_CUSYOMV1; MYBUTTON
CHG_LED: ADAFRUIT_LEDCHIP-LED0603; ADAFRUIT_CHIP-LED0603
C_DELAY: 100nF; EAGLE-LTSPICE_C0402
D1: USBLC6-2SC6Y; SOT95P280X145-6N
D2, D7: ESP32_WROVER_AVX---SD0805S020S1R0_AVX_SD0805S020S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; ESP32_WROVER_AVX---SD0805S020S1R0_AVX_SD0805S020S1R0_0
D3, D4, D5: MBR0530; SOD3716X135N
D6, D8, D9, D10, D11, D12: PGB1010603MR; DIOC1608X36N
EPD_3V3, EPD_3V3_C: TPTP20R; TP20R
EPD_BUSY: TPTP20R; TP20R
EPD_C1, EPD_C2, EPD_C6, EPD_C7, EPD_C8, EPD_C9, EPD_C10, EPD_C11, EPD_C12: 1uF/50V; EAGLE-LTSPICE_C0402
EPD_C5: 0.1uF/50V; EAGLE-LTSPICE_C0402
EPD_CS: TPTP20R; TP20R
EPD_DC: TPTP20R; TP20R
EPD_RST: TPTP20R; TP20R
GND: TPTP20R; TP20R
IC1: BD5229G-TR; SOT95P280X125-5N
IC4: XC6220A331MR-G; SOT95P280X120-5N
INT_RTC: TPTP20R; TP20R
J1: FH34SRJ-24S-0.5SH_99_; FH34SRJ24S05SH99
J2: SAMACSYS_PARTS_USB4110-GF-A; SAMACSYS_PARTS_USB4110GFA
J3: QWIIC_RIGHT_ANGLE; JST04_1MM_RA
J4: 112A-TAAR-R03_ATTEND3DMODEL; 112ATAARR03ATTEND
L1: 744043680IND_4828-WE-TPC_WRE; IND_4828-WE-TPC_WRE
MCP73831: ESP32_WROVER_SPARKFUN-IC-POWER_MCP73831; ESP32_WROVER_SPARKFUN-IC-POWER_SOT23-5
MISO: TPTP20R; TP20R
MOSI: TPTP20R; TP20R
PFMF.050.1: ESP32C6_VARISTORCN1812; ESP32C6_VARISTOR_CT/CN1812
Q1, Q2: 20V/4.2A/52mΩ/1.4W; ESP32_WROVER_SPARKFUN-DISCRETESEMI_SOT23-3
Q3: SI1308EDL-T1-GE3; SOT65P210X110-3N
R1, R1_PINH, R1_PINH1, R2-PINH, R2-PINH1, R4: 10K; ESP32_WROVER_EAGLE-LTSPICE_R0402
R1_BAT: 200; ESP32_WROVER_EAGLE-LTSPICE_R0402
R1_PWRUSB: 100K; ESP32_WROVER_EAGLE-LTSPICE_R0402
R2: 2.2; ESP32_WROVER_EAGLE-LTSPICE_R0402
R2-USB, R2-USB1: 5k1; ESP32_WROVER_EAGLE-LTSPICE_R0402
R2_BAT: 2K; ESP32_WROVER_EAGLE-LTSPICE_R0402
R3: 0.47; ESP32_WROVER_EAGLE-LTSPICE_R0402
R5, R7, R8, R9, R10, R12: ESP32_WROVER_EAGLE-LTSPICE_RR0402; ESP32_WROVER_EAGLE-LTSPICE_R0402
RESET_BUTTON: BUTTON_CUSYOMV1; MYBUTTON
RX: TPTP20R; TP20R
R_BOOT: 10K; ESP32_WROVER_EAGLE-LTSPICE_R0402
R_CAPACITOR: 15; ESP32_WROVER_EAGLE-LTSPICE_R0402
R_CHANGE: 10K; ESP32_WROVER_EAGLE-LTSPICE_R0402
R_CL1: 10K; ESP32_WROVER_EAGLE-LTSPICE_R0402
R_RESET: 10K; ESP32_WROVER_EAGLE-LTSPICE_R0402
SCK: TPTP20R; TP20R
SENSOR2: ESP32_WROVER_BME680_BME680; ESP32_WROVER_BME680_PSON80P300X300X100-8N
SJ1: SJ
TP5: TPTP20R; TP20R
TX: TPTP20R; TP20R
U1: W25Q512JVEIQ; SON127P600X800X80-9N
U2: ESP32-C6-WROOM-1-N8; XCVR_ESP32-C6-WROOM-1-N8
U3: DS3231SN#; SOIC127P1032X265-16N
U4: MAX17048G+T10; SON50P200X200X80-9N
VBAT: TPTP20R; TP20R
VBUS: TPTP20R; TP20R

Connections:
3V3: 3V3.TP, C1_BAT2.1, C3.+, C9.1, D7.2 (ANODE), IC1.2 (VDD), IC4.5 (VOUT), J4.P4 (VDD), Q2.3 (D), R1.2, R1_PINH1.2, R2-PINH1.2, R5.1, R7.1, R8.1, R9.1, R10.1, R12.1, R_BOOT.2, R_CHANGE.2, R_CL1.2, R_RESET.2, U1.3 (!WP!(IO2)), U1.7 (!HOLD!/!RESET!(IO3)), U1.8 (VCC), U2.2 (3V3), U3.2 (VCC)
32KHZ: R2-PINH1.1, U2.9 (IO1), U3.1 (32KHZ)
DN: D1.4 (I/O2_2), J2.A7, J2.B7
DP: D1.6 (I/O1_2), J2.A6, J2.B6
EPD_3V3: C7.1, EPD_3V3.TP, EPD_C5.2, J1.15, J1.16, L1.2, Q2.2 (S)
EPD_3V3_C: EPD_3V3_C.TP, Q2.1 (G), R_CL1.1, U2.18 (IO20)
EPD_BUSY: EPD_BUSY.TP, J1.9, U2.26 (IO3)
EPD_CS: D6.2, EPD_CS.TP, J1.12, R9.2, U2.11 (IO10)
EPD_DC: EPD_DC.TP, J1.11, U2.5 (IO5)
EPD_RST: EPD_RST.TP, J1.10, U2.21 (IO23)
FLASH_CS: D9.2, R5.2, U1.1 (!CS), U2.12 (IO11)
GDR: J1.2, Q3.1 (G), R4.2
GND: BOOT_BUTTON.1, BOOT_BUTTON.2, C1.2, C1_BAT.2, C1_BAT1.1, C1_BAT2.2, C2.2, C2_BAT.2, C3.-, C4_USB.2, C5.2, C5_USB.2, C6.2, C7.2, C8.2, C9.2, C10.2, C10_SUPERCAP.2, CHANGE_BUTTON.1, CHANGE_BUTTON.2, C_DELAY.2, D1.2 (GND), D3.1 (K), D6.1, D8.1, D9.1, D10.1, D11.1, D12.1, EPD_C1.1, EPD_C2.1, GND.TP, IC1.3 (GND), IC4.2 (VSS), J1.8, J1.17, J1.MP1, J1.MP2, J2.A1, J2.A12, J2.B1, J2.B12, J2.MP1, J2.MP2, J2.MP3, J2.MP4, J3.1, J4.G1 (GND_1), J4.G2 (GND_2), J4.G3 (GND_3), J4.G4 (GND_4), J4.P6 (VSS), MCP73831.2 (VSS), R1_PWRUSB.1, R2.1, R2-USB.2, R2-USB1.1, R2_BAT.1, R4.1, RESET_BUTTON.1, RESET_BUTTON.2, SENSOR2.1 (GND), SENSOR2.5 (SDO), SENSOR2.7 (GND), SJ1.1, TP5.TP, U1.4 (GND), U1.9 (EXP), U2.1 (GND), U2.28 (GND), U2.29_1 (GND), U2.29_2 (GND), U2.29_3 (GND), U2.29_4 (GND), U2.29_5 (GND), U2.29_6 (GND), U2.29_7 (GND), U2.29_8 (GND), U2.29_9 (GND), U3.13 (GND), U4.1 (CTG), U4.4 (GND), U4.6 (QSTRT), U4.9 (EP)
GPIO8: R1.1, U2.10 (IO8)
I2C_PW: C1.1, C2.1, R1_PINH.2, R2-PINH.2, SENSOR2.2 (CSB), SENSOR2.6 (VDDIO), SENSOR2.8 (VDD)
I2C_RST: U2.17 (IO19)
INT_RTC: INT_RTC.TP, R1_PINH1.1, U2.8 (IO0), U3.3 (SQW/!INT)
IO/BOOT: BOOT_BUTTON.3, BOOT_BUTTON.4, C6.1, R_BOOT.1, U2.15 (IO9)
IO/CHANGE: C10.1, CHANGE_BUTTON.3, CHANGE_BUTTON.4, R_CHANGE.1, U2.23 (IO15)
MISO: D12.2, J4.P7 (DAT0), MISO.TP, R8.2, U1.2 (DO(IO1)), U2.27 (IO2)
MOSI: D11.2, J1.14, J4.P3 (CMD), MOSI.TP, R7.2, U1.5 (DI(IO0)), U2.7 (IO7)
unnamed: C_DELAY.1, IC1.5 (CT)
unnamed: C1_BAT1.2, D2.1 (CATHODE), IC4.1 (VIN), IC4.3 (CE), Q1.2 (S)
unnamed: MCP73831.1 (STAT), R1_BAT.2
unnamed: J2.B5, R2-USB.1
unnamed: J2.A5, R2-USB1.2
unnamed: C4.1, D3.2 (A), D4.1 (K)
unnamed: CHG_LED.C, R1_BAT.1
unnamed: MCP73831.5 (PROG), R2_BAT.2
unnamed: EPD_C12.2, J1.24
unnamed: EPD_C10.2, J1.22
unnamed: EPD_C8.2, J1.20
unnamed: EPD_C7.2, J1.19
unnamed: EPD_C6.2, J1.18
unnamed: D7.1 (CATHODE), R_CAPACITOR.1
unnamed: EPD_C2.2, J1.5
unnamed: EPD_C1.2, J1.4
unnamed: EPD_C5.1, EPD_C6.1, EPD_C7.1, EPD_C8.1, EPD_C9.1, EPD_C10.1, EPD_C11.1, EPD_C12.1
PREVGH: D5.1 (K), EPD_C9.2, J1.21
PREVGL: D4.2 (A), EPD_C11.2, J1.23
RESE: J1.3, Q3.2 (S), R3.2
RESE': R2.2, R3.1, SJ1.2
RESET: C5.1, IC1.1 (VOUT), RESET_BUTTON.3, RESET_BUTTON.4, R_RESET.1, U2.3 (EN)
RTC_RST: U2.16 (IO18), U3.4 (!RST)
RX: RX.TP, U2.24 (RXD0/GPIO17)
SCK: D10.2, J1.13, J4.P5 (CLK), R12.2, SCK.TP, U1.6 (CLK), U2.6 (IO6)
SCL: J3.4, R2-PINH.1, SENSOR2.4 (SCK), U2.20 (IO22), U3.16 (SCL), U4.7 (SCL)
SDA: J3.2, R1_PINH.1, SENSOR2.3 (SDI), U2.19 (IO21), U3.15 (SDA), U4.8 (SDA)
SRC: C4.2, D5.2 (A), L1.1, Q3.3 (D)
SS_SD: D8.2, J4.P2 (CD/DAT3), R10.2, U2.4 (IO4)
TX: TX.TP, U2.25 (TXD0/GPIO16)
USB-D+: D1.1 (I/O1_1)
USB_D+: U2.14 (IO13)
USB_D-: D1.3 (I/O2_1), U2.13 (IO12)
VBAT: C2_BAT.1, MCP73831.3 (VBAT), Q1.3 (D), U4.2 (CELL), U4.3 (VDD), VBAT.TP
VBUS: C1_BAT.1, C4_USB.1, C5_USB.1, CHG_LED.A, D1.5 (VBUS), D2.2 (ANODE), MCP73831.4 (VIN), PFMF.050.1.2, Q1.1 (G), R1_PWRUSB.2, VBUS.TP
VRTC: C8.1, C10_SUPERCAP.1, R_CAPACITOR.2, U3.14 (VBAT)
VUSB: J2.A4, J2.A9, J2.B4, J2.B9, PFMF.050.1.1

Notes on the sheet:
USB C connector & ESD protection
LDO Voltage Regulator
SD Card
OpenBook Schematic
drawn by: Sebi Huțanu
DeskAssistant v19
Display Type Selector
E-Paper Drive Circuit
Li-Po Battery Charging Controller
ESP32 C6
E-Paped Display Header
DMG2305UX-7
EPD Power
Environmental Sensor BME688
BME688
Voltage Supervisor + Reset &
Boot / IO Button
Battery Charge Level
RTC Module DS3231SN
Test Pads
Qwiic /
Stemma QT
SPI ESD Protection Lines
External NOR Flash 64MB

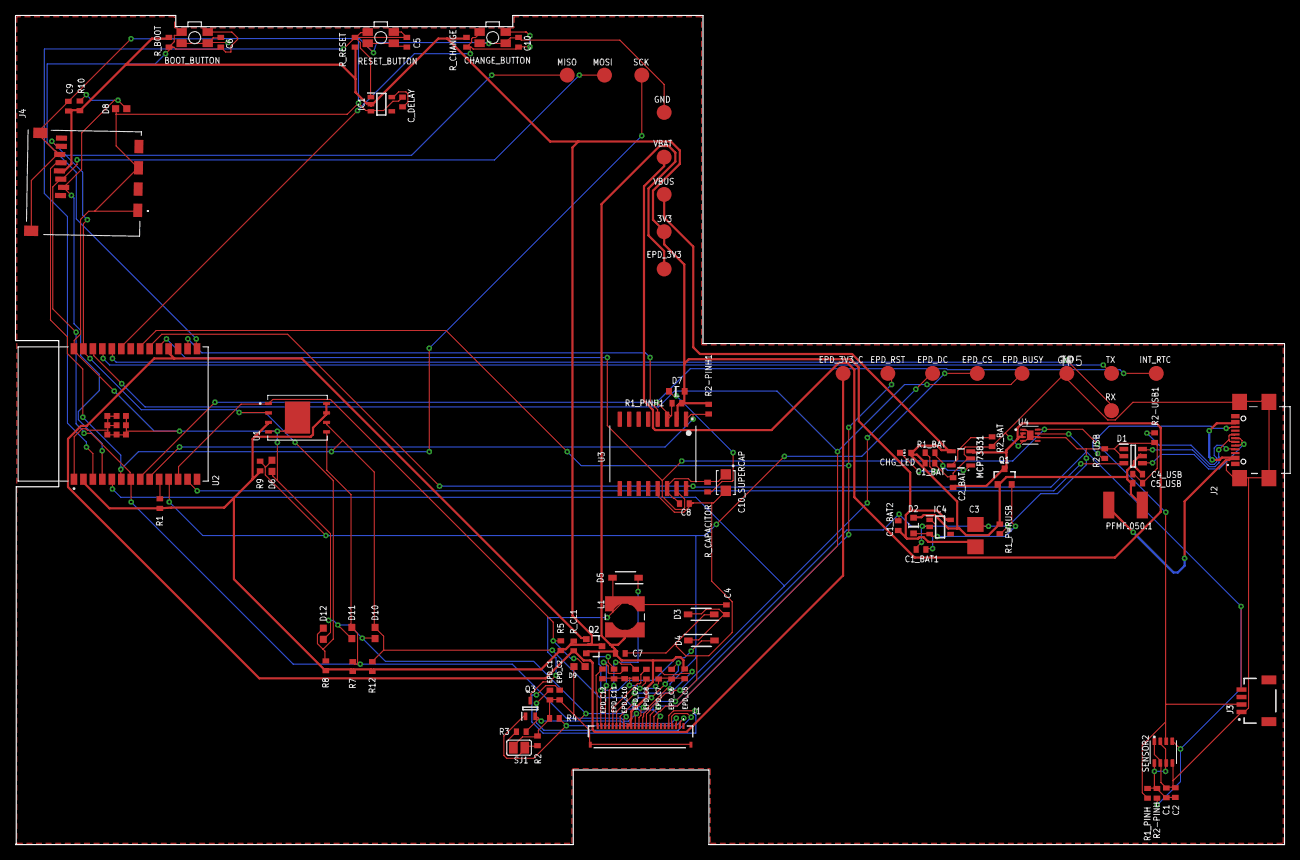
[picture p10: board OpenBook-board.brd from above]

Board: 2 copper layers, 170.2 x 111.2 mm, 103 parts (0 on the bottom side), 55 nets.

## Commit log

2025-04-14 solved ESP32 issue
    [OpenBook-board.brd]
2025-04-14 solved battery issue
    [OpenBook Battery.f3d, OpenBook Battery.f3z]

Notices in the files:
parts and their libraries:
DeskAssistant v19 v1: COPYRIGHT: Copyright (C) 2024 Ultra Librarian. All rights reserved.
